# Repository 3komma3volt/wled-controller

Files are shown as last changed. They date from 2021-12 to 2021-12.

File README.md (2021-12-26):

# wled-controller
A small ESP8266 controller with step-down for use with [WLED](https://github.com/Aircoookie/WLED) firmware made with KICAD 6

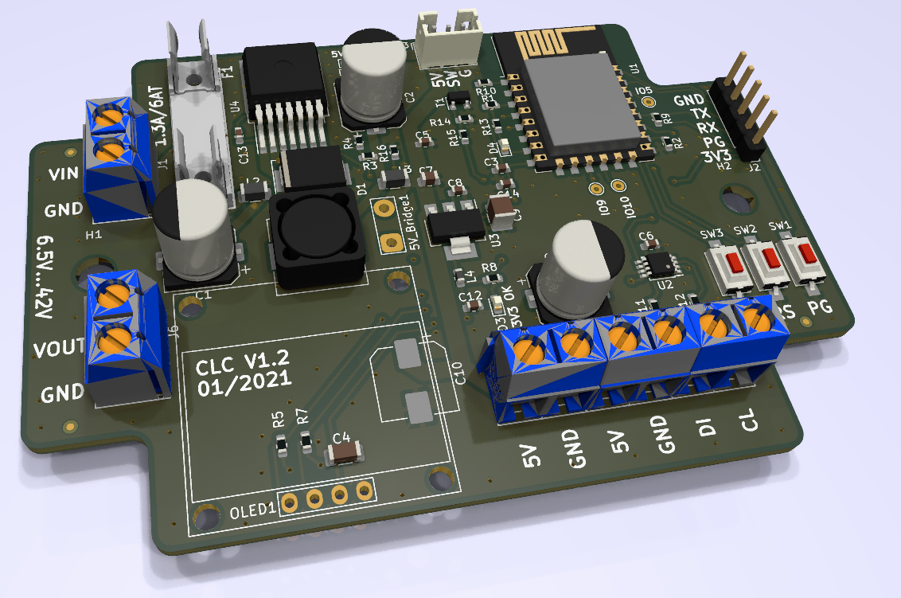
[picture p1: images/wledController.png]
wled-controller


# Intro
This board was designed for a christmas lightshow and 17 of them were used. They were supplied from a central 24V power supply and the supply was chained from prop to prop. This made wireing very easy. 
The included 5V regulator supplies up to 5A which is pretty enough for some light props.
The [KICAD](https://www.kicad.org) files include LCSC component numbers for direct ordering at [JLCPCB](https://jlcpcb.com)
The board shape is made for some cheap enclosures

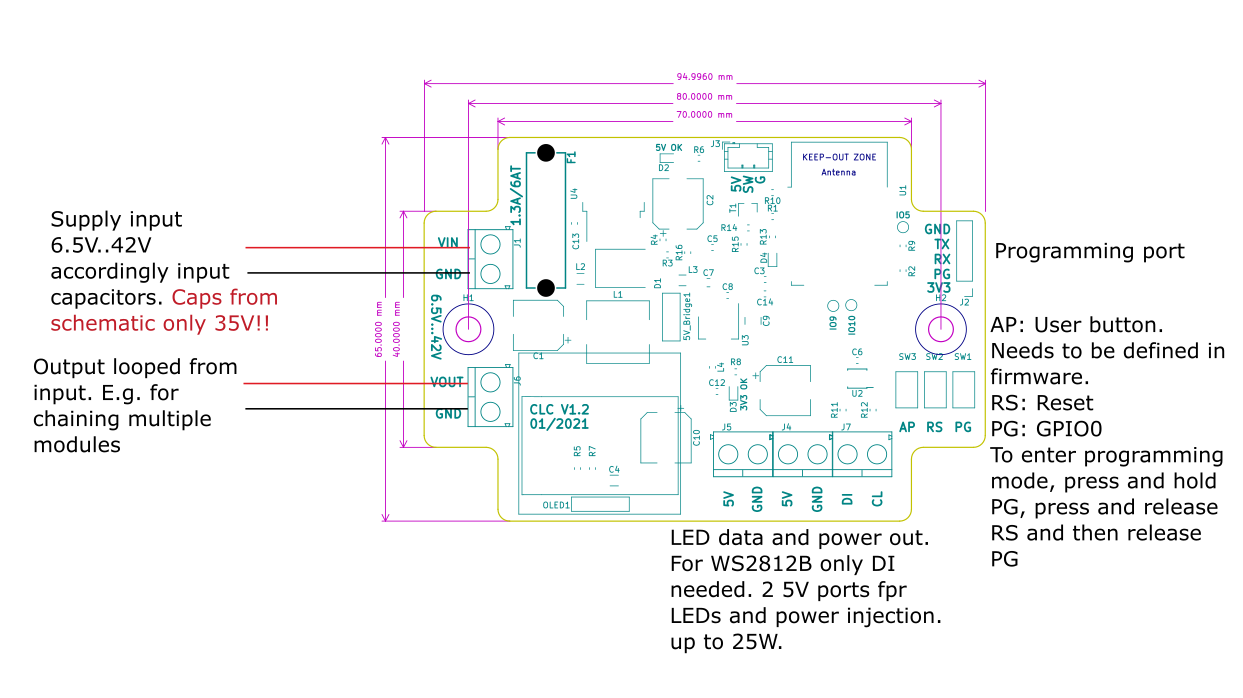
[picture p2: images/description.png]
wled-desc


# Usage
First decide if you want to use the voltage regulator. In some cases, you need more power and then you can remove/not populate the U4 regulator and solder the 5V_Bridge1 on the board. Then the VIN supply must not more than 12V!
With the brige, the voltage on the screw terminals is the same than VIN. So you could use 12V pixels whith this board or a powerful 5V supply. The ESP is supplied from an other voltage regulator.
Without brige, the voltage regulator has to be mounted. Use following fusing for F1:
- 24V input: 1.3A
- 5V or 12V input (with bridge and no U4 mounted): 5A or greater, accordingly to your used power supply / or pixels
An OLED can be mounted but have to be defined in the firmware
A MOSFET can be populated and switch some small loads (connected to J3) and have to be defined in firmware

## Programming
For programming an USB to UART converter is needed. Use following steps:
- EITHER supply from VIN or supply 3.3V to J2 (e.g. from an USB/UART converter)
- Connect GND, RX, TX from the USB/UART to J2
- Press and hold PG, press and release RS, release RS. The EPS should now be in programming mode
- Program accordingly WLED manual and press RS after programming. Now the board should open an AP

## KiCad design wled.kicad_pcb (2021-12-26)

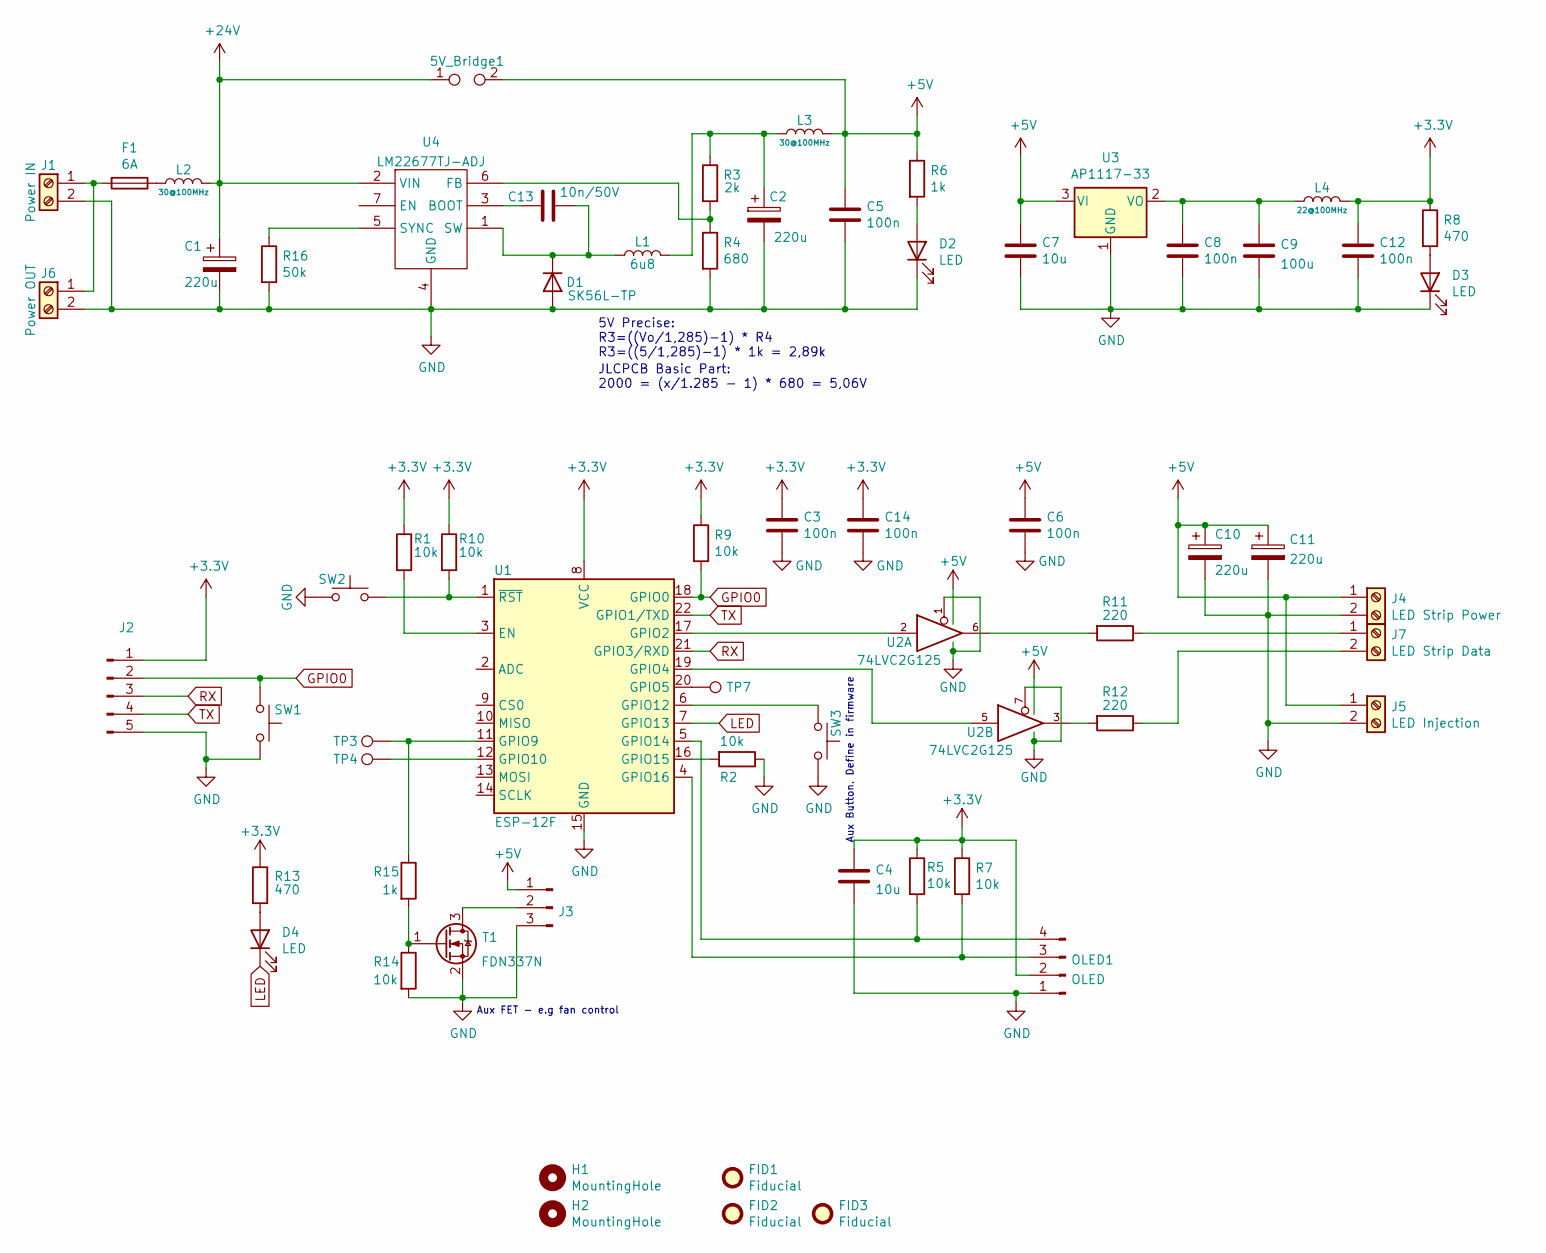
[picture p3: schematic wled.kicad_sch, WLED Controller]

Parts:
5V_Bridge1: TestPoint_2Pole; TestPoint_2Pads_Pitch5.08mm_Drill1.3mm
C1, C2, C10, C11: 220u; CP_Elec_8x10; LCSC C311611
C3, C5, C6, C8, C12, C14: 100n; C_0603_1608Metric; LCSC C14663
C4: 10u; C_1206_3216Metric; LCSC C19702
C7: 10u; C_0805_2012Metric; LCSC C19702
C9: 100u; C_1210_3225Metric; LCSC C16133
C13: 10n/50V; C_0603_1608Metric; LCSC C57112
D1: SK56L-TP; D_SMC; LCSC C669020
D2, D3, D4: LED; LED_0603_1608Metric; LCSC C72038
F1: 6A; FX0321
FID1, FID2, FID3: Fiducial; Fiducial_0.75mm_Mask1.5mm
H1, H2: MountingHole; MountingHole_4.3mm_M4
J1: Power IN; OSTTC020162
J2: Conn_01x05_Male; PinHeader_1x05_P2.54mm_Vertical
J3: Conn_01x03_Male; JST_PH_B3B-PH-K_1x03_P2.00mm_Vertical
J4: LED Strip Power; OSTTC020162
J5: LED Injection; OSTTC020162
J6: Power OUT; OSTTC020162
J7: LED Strip Data; OSTTC020162
L1: 6u8; L_10.4x10.4_H4.8; LCSC C207852
L2, L3: 30@100MHz; L_1206_3216Metric; LCSC C316417
L4: 22@100MHz; L_0603_1608Metric; LCSC C73100
OLED1: OLED; 128x64OLED
R1, R2, R5, R7, R9, R10, R14: 10k; R_0603_1608Metric; LCSC C25804
R3: 2k; R_0603_1608Metric; LCSC C22975
R4: 680; R_0603_1608Metric; LCSC C23228
R6, R15: 1k; R_0603_1608Metric; LCSC C21190
R8, R13: 470; R_0603_1608Metric; LCSC C23179
R11, R12: 220; R_0603_1608Metric; LCSC C22962
R16: 50k; R_0603_1608Metric; LCSC C23196
SW1, SW2, SW3: SW_Push; SW_SPST_CK_RS282G05A3; LCSC C520860
T1: FDN337N; SOT-23; LCSC C475694
TP3, TP4, TP7: TestPoint; TestPoint_THTPad_D1.5mm_Drill0.7mm
U1: ESP-12F; ESP-12E; LCSC C82891
U2: 74LVC2G125; TSSOP-8_3x3mm_P0.65mm; LCSC C206035
U3: AP1117-33; SOT-223-3_TabPin2; LCSC C6186
U4: LM22677TJ-ADJ; TO-263-7_TabPin4

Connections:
+3V3: C3.1, C4.1, C12.1, C14.1, J2.1, L4.2, OLED1.2, R1.1, R5.1, R7.1, R8.1, R9.1, R10.1, R13.1, U1.8 (VCC)
+5V: 5V_Bridge1.2, C5.1, C6.1, C7.1, C10.1, C11.1, J3.1, J4.1, J5.1, L3.2, R6.1, U2.8 (VCC), U3.3 (VI)
+24V: 5V_Bridge1.1, C1.1, L2.2, U4.2 (VIN)
GND: C1.2, C2.2, C3.2, C4.2, C5.2, C6.2, C7.2, C8.2, C9.2, C10.2, C11.2, C12.2, C14.2, D1.2 (A), D2.1 (K), D3.1 (K), J1.2, J2.5, J3.3, J4.2, J5.2, J6.2, OLED1.1, R2.1, R4.2, R14.2, R16.2, SW1.2, SW2.2, SW3.1, T1.2 (S), U1.15 (GND), U2.1, U2.4 (GND), U2.7, U3.1 (GND), U4.4 (GND)
GPIO0: J2.2, R9.2, SW1.1, U1.18 (GPIO0)
LED: D4.1 (K), U1.7 (GPIO13)
unnamed: C2.1, L1.2, L3.1, R3.1
unnamed: C8.1, C9.1, L4.1, U3.2 (VO)
unnamed: C13.1, U4.3 (BOOT)
unnamed: C13.2, D1.1 (K), L1.1, U4.1 (SW)
unnamed: D2.2 (A), R6.2
unnamed: D3.2 (A), R8.2
unnamed: D4.2 (A), R13.2
unnamed: F1.1, L2.1
unnamed: F1.2, J1.1, J6.1
unnamed: J3.2, T1.3 (D)
unnamed: J7.1, R11.1
unnamed: J7.2, R12.1
unnamed: OLED1.3, R7.2, U1.4 (GPIO16)
unnamed: OLED1.4, R5.2, U1.5 (GPIO14)
unnamed: R1.2, U1.3 (EN)
unnamed: R2.2, U1.16 (GPIO15)
unnamed: R3.2, R4.1, U4.6 (FB)
unnamed: R10.2, SW2.1, U1.1 (~RST)
unnamed: R11.2, U2.6
unnamed: R12.2, U2.3
unnamed: R14.1, R15.2, T1.1 (G)
unnamed: R15.1, TP3.1, U1.11 (GPIO9)
unnamed: R16.1, U4.5 (SYNC)
unnamed: SW3.2, U1.6 (GPIO12)
unnamed: TP4.1, U1.12 (GPIO10)
unnamed: TP7.1, U1.20 (GPIO5)
unnamed: U1.17 (GPIO2), U2.2
unnamed: U1.19 (GPIO4), U2.5
RX: J2.3, U1.21 (GPIO3/RXD)
TX: J2.4, U1.22 (GPIO1/TXD)

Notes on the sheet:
Aux Button. Define in firmware
JLCPCB Basic Part: 2000 = (x/1.285 - 1) * 680 = 5,06V
5V Precise: R3=((Vo/1,285)-1) * R4 R3=((5/1,285)-1) * 1k = 2,89k
Aux FET - e.g fan control

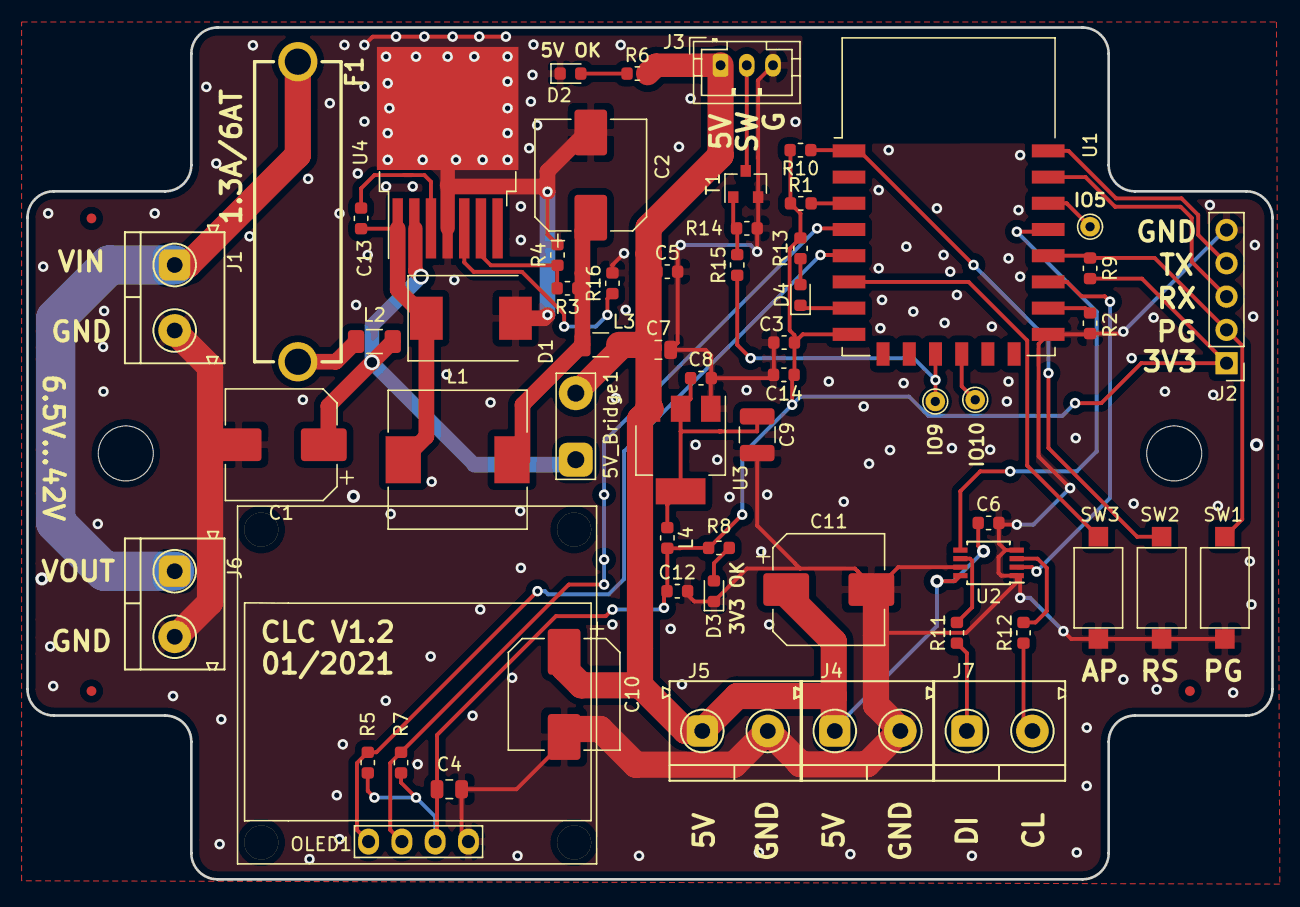
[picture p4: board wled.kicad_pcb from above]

Board: 2 copper layers, 95.0 x 65.0 mm, 64 parts (0 on the bottom side), 36 nets.
